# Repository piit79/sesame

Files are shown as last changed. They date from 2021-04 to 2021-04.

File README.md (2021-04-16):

# Sesame

[][cc-by-nc-sa]

### Alice like ergo keyboard using only THT parts



Modified by [u/piit79](https://reddit.com/user/piit79) to use components more in line
with other similar kits (Mysterium etc.).

### Partslist
 |Count|Part|Reference|LCSC Part #|
 |-|-|-|-|
 |1|ATmega32A 40 pin DIP (32L works too)|U1|C12703|
 |1|40 pin DIP socket (optional but highly recommended)|U1|C2332|
 |1|USB4085-GF-A USB Type-C socket|USB1|
 |1|500 mA polyfuse|F1|C369081|
 |2|6mm momentary push buttons|Boot,Reset|C620202|
 |1|16 MHz quartz crystal|XTAL1|C16212|
 |1|4.7 uF electrolytic capacitor|C1|C47879|
 |2|100 nF ceramic disk capacitor|C2,C3|C353913|
 |2|22 pF ceramic disk capacitor|C4,C5|C254096|
 |1|1.5 kΩ resistor|R1|C58620|
 |2|75 Ω resistor|R2,R3|C433693|
 |2|5.1 kΩ resistor|R4,R5|C714593|
 |1|10 kΩ resistor|R6|C119347|
 |2|3.6 V zener diode (DO-35 BZX55C3V6)|D1,D2|C2508|
 |66|universal switching diode (DO-35 1N4148)|D3-D68|C14516|
 
 The USB port can be found here:  
https://www.digikey.com/en/products/detail/gct/USB4085-GF-A/9859733

-----




This work is licensed under a
[Creative Commons Attribution-NonCommercial-ShareAlike 4.0 International License][cc-by-nc-sa].

[][cc-by-nc-sa]

[cc-by-nc-sa]: http://creativecommons.org/licenses/by-nc-sa/4.0/
[cc-by-nc-sa-image]: https://licensebuttons.net/l/by-nc-sa/4.0/88x31.png
[cc-by-nc-sa-shield]: https://img.shields.io/badge/License-CC%20BY--NC--SA%204.0-lightgrey.svg

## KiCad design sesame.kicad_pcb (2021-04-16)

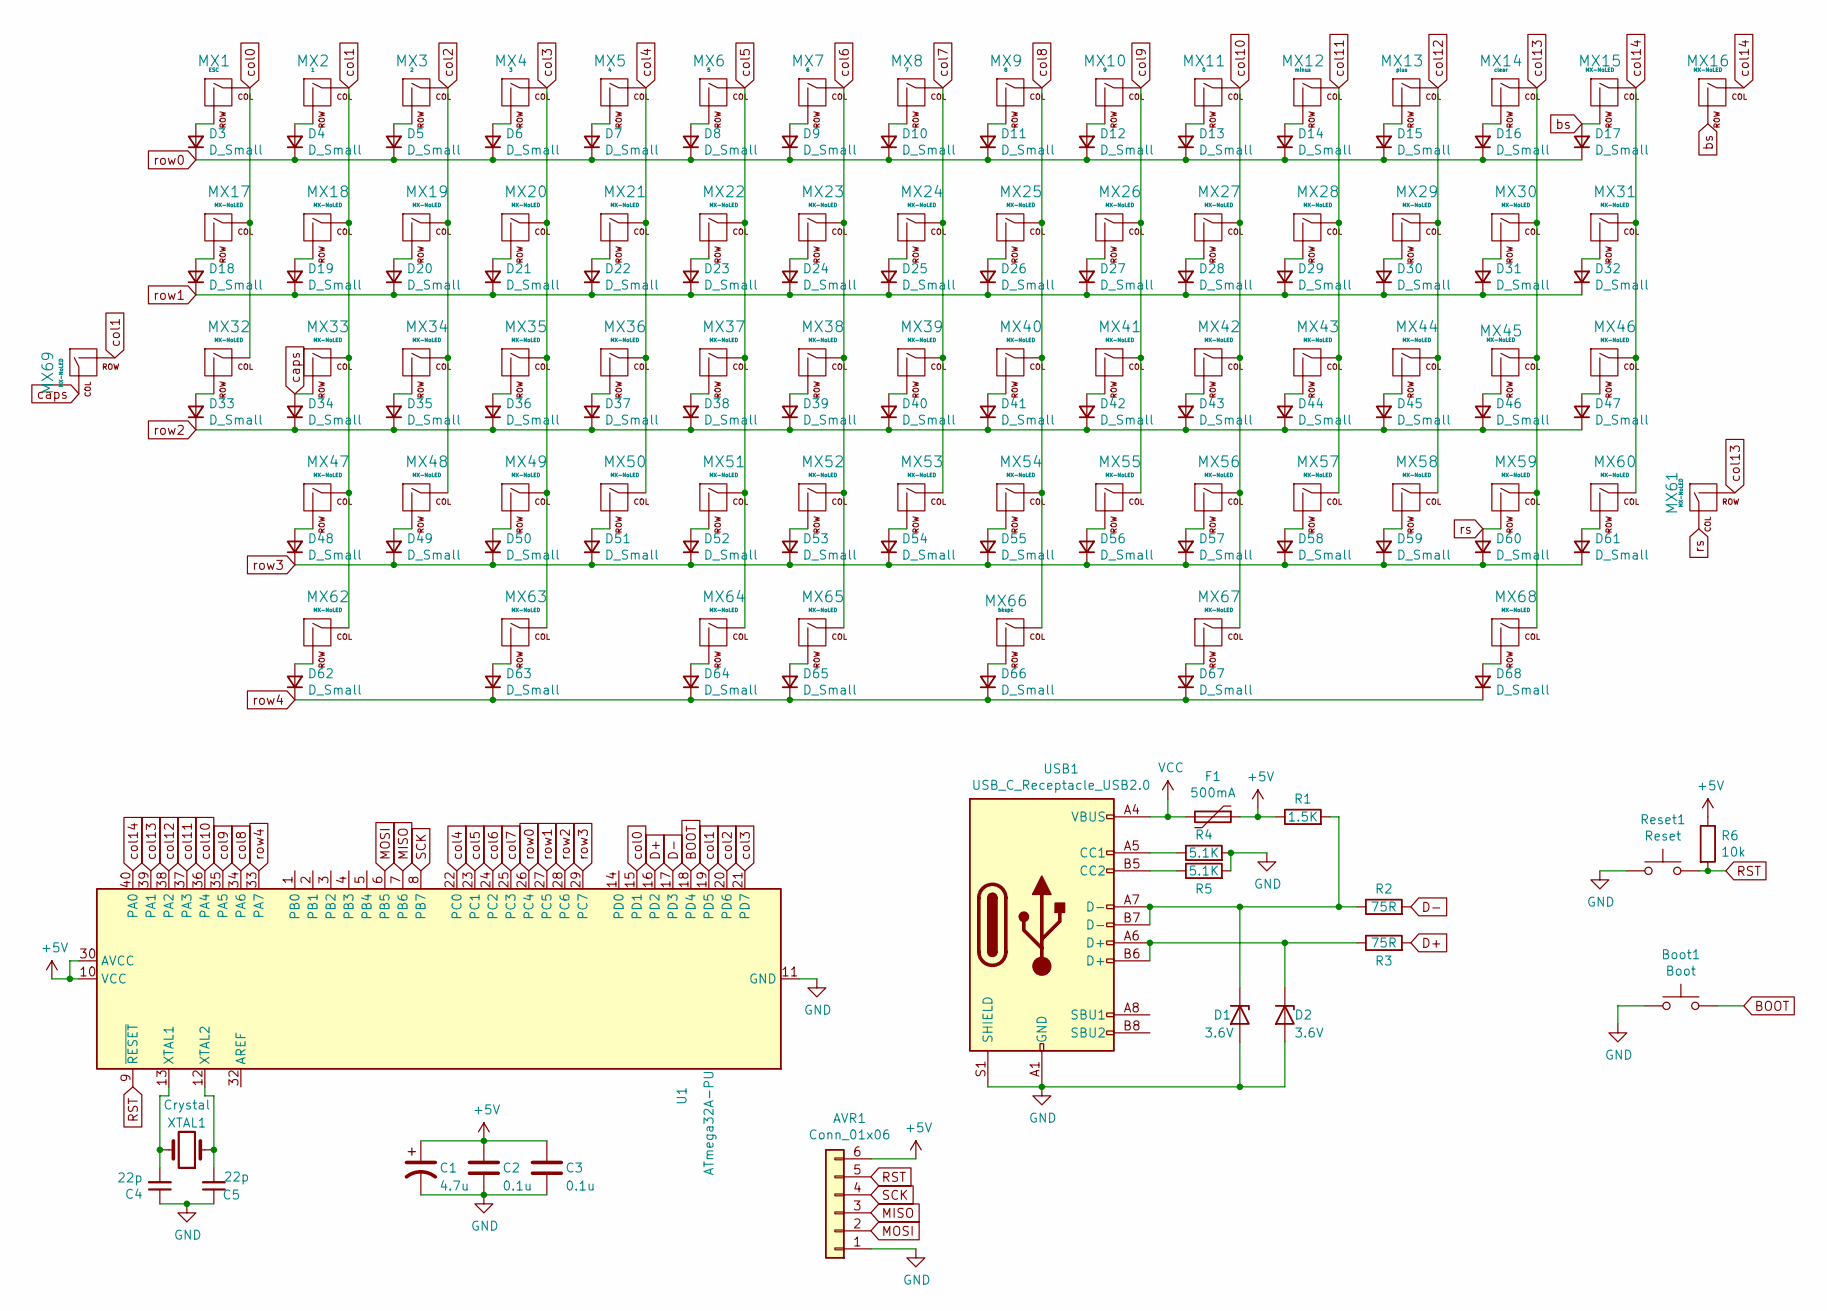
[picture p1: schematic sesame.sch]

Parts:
AVR1: Conn_01x06; PinHeader_1x06_P2.54mm_Vertical
Boot1: Boot; SW_PUSH_6mm
C1: 4.7u; CP_Radial_D4.0mm_P1.50mm
C2, C3: 0.1u; C_Disc_D3.0mm_W2.0mm_P2.50mm
C4, C5: 22p; C_Disc_D6.0mm_W2.5mm_P5.00mm
D1, D2: 3.6V; D_DO-35_SOD27_P7.62mm_Horizontal
D3, D4, D5, D6, D7, D8, D9, D10, D11, D12, D13, D14, D15, D16, D17, D18, D19, D20, D21, D22, D23, D24, D25, D26, D27, D28, D29, D30, D31, D32, D33, D34, D35, D36, D37, D38, D39, D40, D41, D42, D43, D44, D45, D46, D47, D48, D49, D50, D51, D52, D53, D54, D55, D56, D57, D58, D59, D60, D61, D62, D63, D64, D65, D66, D67, D68: D_Small; D_DO-35_SOD27_P7.62mm_Horizontal
F1: 500mA; Fuse_Littelfuse_395Series
MX1: ESC; MXOnly-1U-NoLED
MX2: 1; MXOnly-1U-NoLED
MX3: 2; MXOnly-1U-NoLED
MX4: 3; MXOnly-1U-NoLED
MX5: 4; MXOnly-1U-NoLED
MX6: 5; MXOnly-1U-NoLED
MX7: 6; MXOnly-1U-NoLED
MX8: 7; MXOnly-1U-NoLED
MX9: 8; MXOnly-1U-NoLED
MX10: 9; MXOnly-1U-NoLED
MX11: 0; MXOnly-1U-NoLED
MX12: minus; MXOnly-1U-NoLED
MX13: plus; MXOnly-1U-NoLED
MX14: clear; MXOnly-1U-NoLED
MX15: MX-NoLED; MXOnly-2U-NoLED
MX16, MX17, MX19, MX20, MX21, MX22, MX23, MX24, MX25, MX26, MX27, MX28, MX29, MX30, MX32, MX34, MX35, MX36, MX37, MX38, MX39, MX40, MX41, MX42, MX43, MX44, MX45, MX48, MX49, MX50, MX51, MX52, MX53, MX54, MX55, MX56, MX57, MX58, MX60, MX62, MX63, MX67, MX68: MX-NoLED; MXOnly-1U-NoLED
MX18, MX31: MX-NoLED; MXOnly-1.5U-NoLED
MX33, MX59: MX-NoLED; MXOnly-1.75U-NoLED
MX46: MX-NoLED; MXOnly-2.25U-ReversedStabilizers-NoLED
MX47: MX-NoLED; MXOnly-2.25U-NoLED
MX61: MX-NoLED; MXOnly-2.75U-NoLED
MX64: MX-NoLED; MXOnly-2U-ReversedStabilizers-NoLED
MX65, MX69: MX-NoLED; MXOnly-1.25U-NoLED
MX66: bkspc; MXOnly-2.25U-ReversedStabilizers-NoLED
R1: 1.5K; R_Axial_DIN0207_L6.3mm_D2.5mm_P10.16mm_Horizontal
R2, R3: 75R; R_Axial_DIN0207_L6.3mm_D2.5mm_P10.16mm_Horizontal
R4, R5: 5.1K; R_Axial_DIN0207_L6.3mm_D2.5mm_P10.16mm_Horizontal
R6: 10k; R_Axial_DIN0207_L6.3mm_D2.5mm_P10.16mm_Horizontal
Reset1: Reset; SW_PUSH_6mm
U1: ATmega32A-PU; DIP-40_W15.24mm
USB1: USB_C_Receptacle_USB2.0; USB_C_GCT_USB4085
XTAL1: Crystal; Crystal_HC49-4H_Vertical

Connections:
+5V: AVR1.6, C1.1, C2.1, C3.1, F1.1, R1.1, R6.1, U1.10 (VCC), U1.30 (AVCC)
BOOT: Boot1.2, U1.18 (PD4)
D+: R3.2, U1.16 (PD2)
D-: R2.2, U1.17 (PD3)
GND: AVR1.1, Boot1.1, C1.2, C2.2, C3.2, C4.1, C5.1, D1.2 (A), D2.2 (A), R4.2, R5.2, Reset1.1, U1.11 (GND), U1.31 (GND), USB1.A1 (GND), USB1.A12 (GND), USB1.B1 (GND), USB1.B12 (GND), USB1.S1 (SHIELD)
MISO: AVR1.3, U1.7 (PB6)
MOSI: AVR1.2, U1.6 (PB5)
unnamed: C4.2, U1.13 (XTAL1), XTAL1.2
unnamed: C5.2, U1.12 (XTAL2), XTAL1.1
unnamed: D1.1 (K), R1.2, R2.1, USB1.A7 (D-), USB1.B7 (D-)
unnamed: D2.1 (K), R3.1, USB1.A6 (D+), USB1.B6 (D+)
unnamed: D3.2 (A), MX1.2 (ROW)
unnamed: D4.2 (A), MX2.2 (ROW)
unnamed: D5.2 (A), MX3.2 (ROW)
unnamed: D6.2 (A), MX4.2 (ROW)
unnamed: D7.2 (A), MX5.2 (ROW)
unnamed: D8.2 (A), MX6.2 (ROW)
unnamed: D9.2 (A), MX7.2 (ROW)
unnamed: D10.2 (A), MX8.2 (ROW)
unnamed: D11.2 (A), MX9.2 (ROW)
unnamed: D12.2 (A), MX10.2 (ROW)
unnamed: D13.2 (A), MX11.2 (ROW)
unnamed: D14.2 (A), MX12.2 (ROW)
unnamed: D15.2 (A), MX13.2 (ROW)
unnamed: D16.2 (A), MX14.2 (ROW)
unnamed: D18.2 (A), MX17.2 (ROW)
unnamed: D19.2 (A), MX18.2 (ROW)
unnamed: D20.2 (A), MX19.2 (ROW)
unnamed: D21.2 (A), MX20.2 (ROW)
unnamed: D22.2 (A), MX21.2 (ROW)
unnamed: D23.2 (A), MX22.2 (ROW)
unnamed: D24.2 (A), MX23.2 (ROW)
unnamed: D25.2 (A), MX24.2 (ROW)
unnamed: D26.2 (A), MX25.2 (ROW)
unnamed: D27.2 (A), MX26.2 (ROW)
unnamed: D28.2 (A), MX27.2 (ROW)
unnamed: D29.2 (A), MX28.2 (ROW)
unnamed: D30.2 (A), MX29.2 (ROW)
unnamed: D31.2 (A), MX30.2 (ROW)
unnamed: D32.2 (A), MX31.2 (ROW)
unnamed: D33.2 (A), MX32.2 (ROW)
unnamed: D35.2 (A), MX34.2 (ROW)
unnamed: D36.2 (A), MX35.2 (ROW)
unnamed: D37.2 (A), MX36.2 (ROW)
unnamed: D38.2 (A), MX37.2 (ROW)
unnamed: D39.2 (A), MX38.2 (ROW)
unnamed: D40.2 (A), MX39.2 (ROW)
unnamed: D41.2 (A), MX40.2 (ROW)
unnamed: D42.2 (A), MX41.2 (ROW)
unnamed: D43.2 (A), MX42.2 (ROW)
unnamed: D44.2 (A), MX43.2 (ROW)
unnamed: D45.2 (A), MX44.2 (ROW)
unnamed: D46.2 (A), MX45.2 (ROW)
unnamed: D47.2 (A), MX46.2 (ROW)
unnamed: D48.2 (A), MX47.2 (ROW)
unnamed: D49.2 (A), MX48.2 (ROW)
unnamed: D50.2 (A), MX49.2 (ROW)
unnamed: D51.2 (A), MX50.2 (ROW)
unnamed: D52.2 (A), MX51.2 (ROW)
unnamed: D53.2 (A), MX52.2 (ROW)
unnamed: D54.2 (A), MX53.2 (ROW)
unnamed: D55.2 (A), MX54.2 (ROW)
unnamed: D56.2 (A), MX55.2 (ROW)
unnamed: D57.2 (A), MX56.2 (ROW)
unnamed: D58.2 (A), MX57.2 (ROW)
unnamed: D59.2 (A), MX58.2 (ROW)
unnamed: D61.2 (A), MX60.2 (ROW)
unnamed: D62.2 (A), MX62.2 (ROW)
unnamed: D63.2 (A), MX63.2 (ROW)
unnamed: D64.2 (A), MX64.2 (ROW)
unnamed: D65.2 (A), MX65.2 (ROW)
unnamed: D66.2 (A), MX66.2 (ROW)
unnamed: D67.2 (A), MX67.2 (ROW)
unnamed: D68.2 (A), MX68.2 (ROW)
unnamed: R4.1, USB1.A5 (CC1)
unnamed: R5.1, USB1.B5 (CC2)
RST: AVR1.5, R6.2, Reset1.2, U1.9 (~RESET)
SCK: AVR1.4, U1.8 (PB7)
VCC: F1.2, USB1.A4 (VBUS), USB1.A9 (VBUS), USB1.B4 (VBUS), USB1.B9 (VBUS)
bs: D17.2 (A), MX15.2 (ROW), MX16.2 (ROW)
caps: D34.2 (A), MX33.2 (ROW), MX69.1 (COL)
col0: MX1.1 (COL), MX17.1 (COL), MX32.1 (COL), U1.15 (PD1)
col1: MX2.1 (COL), MX18.1 (COL), MX33.1 (COL), MX47.1 (COL), MX62.1 (COL), MX69.2 (ROW), U1.19 (PD5)
col2: MX3.1 (COL), MX19.1 (COL), MX34.1 (COL), MX48.1 (COL), U1.20 (PD6)
col3: MX4.1 (COL), MX20.1 (COL), MX35.1 (COL), MX49.1 (COL), MX63.1 (COL), U1.21 (PD7)
col4: MX5.1 (COL), MX21.1 (COL), MX36.1 (COL), MX50.1 (COL), U1.22 (PC0)
col5: MX6.1 (COL), MX22.1 (COL), MX37.1 (COL), MX51.1 (COL), MX64.1 (COL), U1.23 (PC1)
col6: MX7.1 (COL), MX23.1 (COL), MX38.1 (COL), MX52.1 (COL), MX65.1 (COL), U1.24 (PC2)
col7: MX8.1 (COL), MX24.1 (COL), MX39.1 (COL), MX53.1 (COL), U1.25 (PC3)
col8: MX9.1 (COL), MX25.1 (COL), MX40.1 (COL), MX54.1 (COL), MX66.1 (COL), U1.34 (PA6)
col9: MX10.1 (COL), MX26.1 (COL), MX41.1 (COL), MX55.1 (COL), U1.35 (PA5)
col10: MX11.1 (COL), MX27.1 (COL), MX42.1 (COL), MX56.1 (COL), MX67.1 (COL), U1.36 (PA4)
col11: MX12.1 (COL), MX28.1 (COL), MX43.1 (COL), MX57.1 (COL), U1.37 (PA3)
col12: MX13.1 (COL), MX29.1 (COL), MX44.1 (COL), MX58.1 (COL), U1.38 (PA2)
col13: MX14.1 (COL), MX30.1 (COL), MX45.1 (COL), MX59.1 (COL), MX61.2 (ROW), MX68.1 (COL), U1.39 (PA1)
col14: MX15.1 (COL), MX16.1 (COL), MX31.1 (COL), MX46.1 (COL), MX60.1 (COL), U1.40 (PA0)
row0: D3.1 (K), D4.1 (K), D5.1 (K), D6.1 (K), D7.1 (K), D8.1 (K), D9.1 (K), D10.1 (K), D11.1 (K), D12.1 (K), D13.1 (K), D14.1 (K), D15.1 (K), D16.1 (K), D17.1 (K), U1.26 (PC4)
row1: D18.1 (K), D19.1 (K), D20.1 (K), D21.1 (K), D22.1 (K), D23.1 (K), D24.1 (K), D25.1 (K), D26.1 (K), D27.1 (K), D28.1 (K), D29.1 (K), D30.1 (K), D31.1 (K), D32.1 (K), U1.27 (PC5)
row2: D33.1 (K), D34.1 (K), D35.1 (K), D36.1 (K), D37.1 (K), D38.1 (K), D39.1 (K), D40.1 (K), D41.1 (K), D42.1 (K), D43.1 (K), D44.1 (K), D45.1 (K), D46.1 (K), D47.1 (K), U1.28 (PC6)
row3: D48.1 (K), D49.1 (K), D50.1 (K), D51.1 (K), D52.1 (K), D53.1 (K), D54.1 (K), D55.1 (K), D56.1 (K), D57.1 (K), D58.1 (K), D59.1 (K), D60.1 (K), D61.1 (K), U1.29 (PC7)
row4: D62.1 (K), D63.1 (K), D64.1 (K), D65.1 (K), D66.1 (K), D67.1 (K), D68.1 (K), U1.33 (PA7)
rs: D60.2 (A), MX59.2 (ROW), MX61.1 (COL)

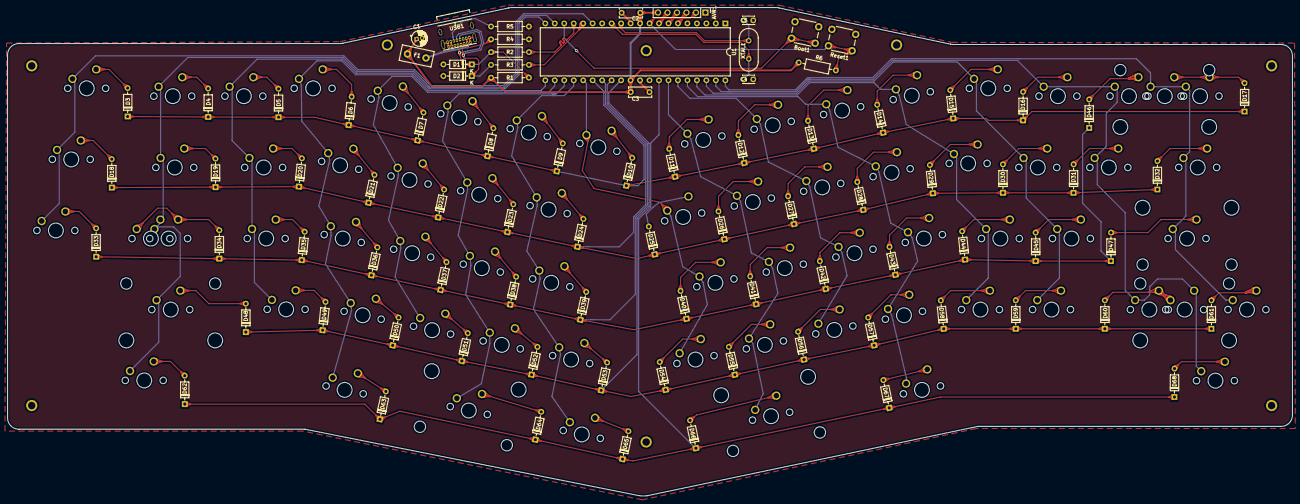
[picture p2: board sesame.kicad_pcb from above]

Board: 2 copper layers, 344.4 x 130.9 mm, 155 parts (0 on the bottom side), 102 nets.

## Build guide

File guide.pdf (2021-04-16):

## Sesame Ergo build guide

Very quick and dirty build guide. Modified by piit79.
If you need any help feel free to contact me on Discord (piit79#2997) or on Reddit (u/piit79).

### Parts included:

1 | Sesame PCB
1 | Sesame Backplate (Logo on the back)
1 | Sesame FR4 switchplate
1 | Acrylic cover window
1 | Backplate foam (optional)
14 | M2x4 mm screws for the backplate and window standoffs
2 | M2x6 mm screws for the acrylic window
6 | M2x6 standoffs for the backplate
2 | M2x10 standoffs for the acrylic window
1 | ATmega32A controller
1 | 40 pin DIP socket (optional but highly recommended)
1 | USB Type-C socket (USB4085-GF-A)
1 | 500 mA polyfuse
2 | 6mm momentary push buttons
1 | 16 MHz quartz crystal
1 | 4.7 uF electrolytic capacitor
2 | 100 nF ceramic disk capacitor
2 | 22 pF ceramic disk capacitor
1 | 10 kΩ resistor
1 | 1.5 kΩ resistor
2 | 75 Ω resistor
2 | 5.1 kΩ resistor
2 | 3.6 V zener diode (DO-35 BZX55C3V6)
68 | universal switching diode (DO-35 1N4148)

You only need 66 of the switching diodes for the board. The rest are replacements in case one gets damaged during soldering.

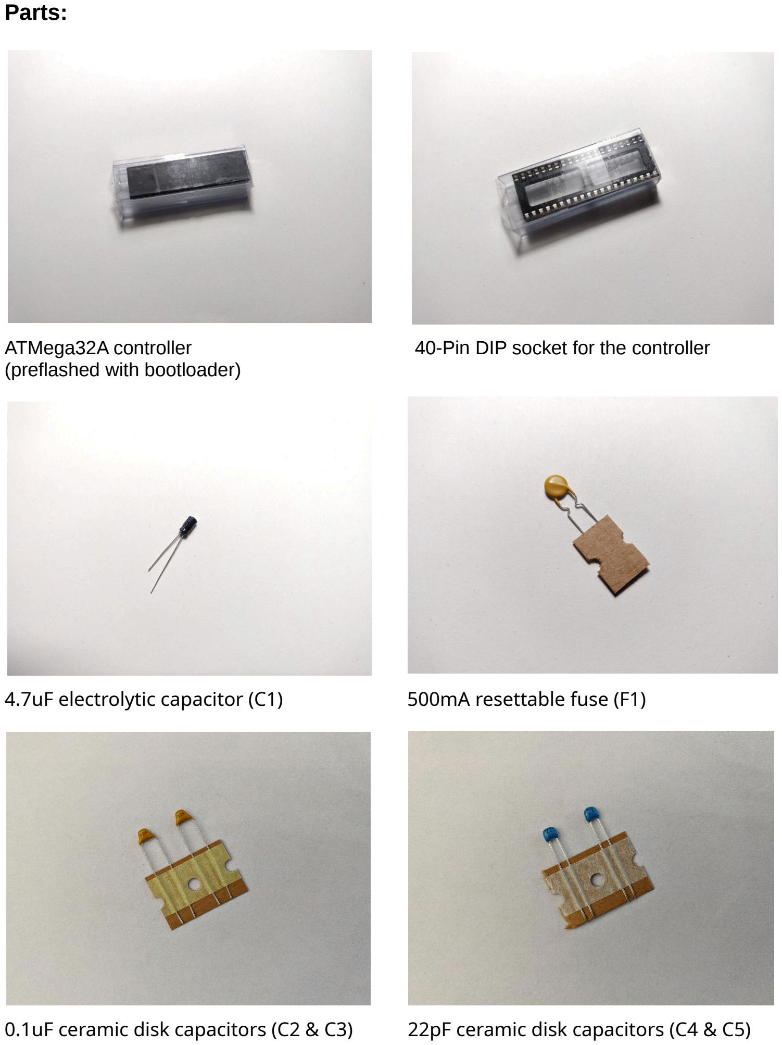
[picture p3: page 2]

Parts:

ATMega32A controller | 40-Pin DIP socket for the controller
(preflashed with bootloader)
4.7uF electrolytic capacitor (C1) | 500mA resettable fuse (F1)
0.1uF ceramic disk capacitors (C2 & C3) | 22pF ceramic disk capacitors (C4 & C5)

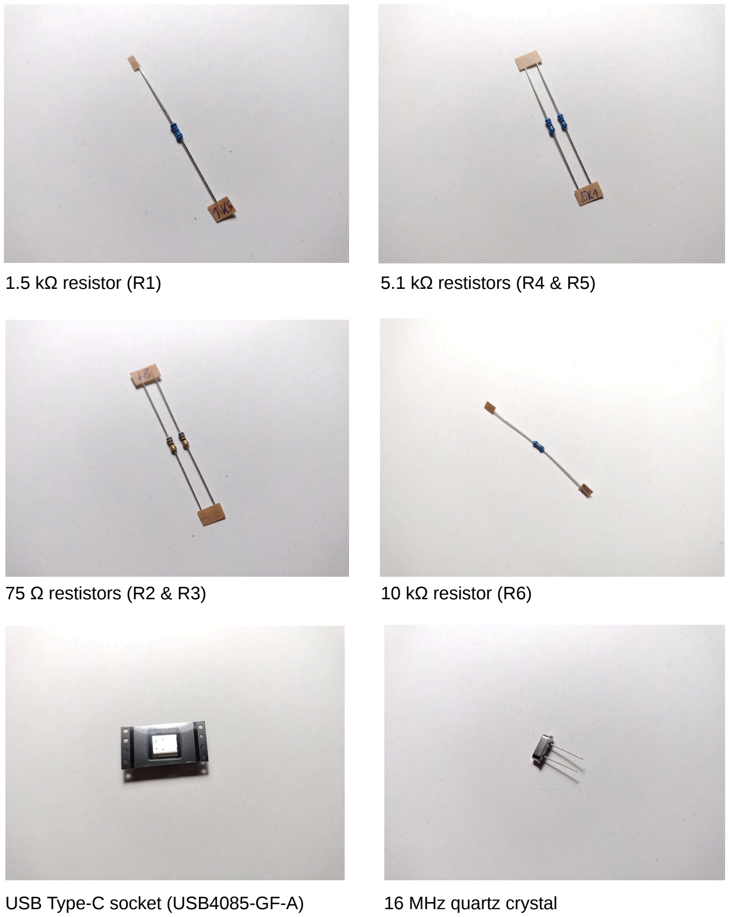
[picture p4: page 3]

1.5 kΩ resistor (R1) | 5.1 kΩ restistors (R4 & R5)
75 Ω restistors (R2 & R3) | 10 kΩ resistor (R6)
USB Type-C socket (USB4085-GF-A) | 16 MHz quartz crystal

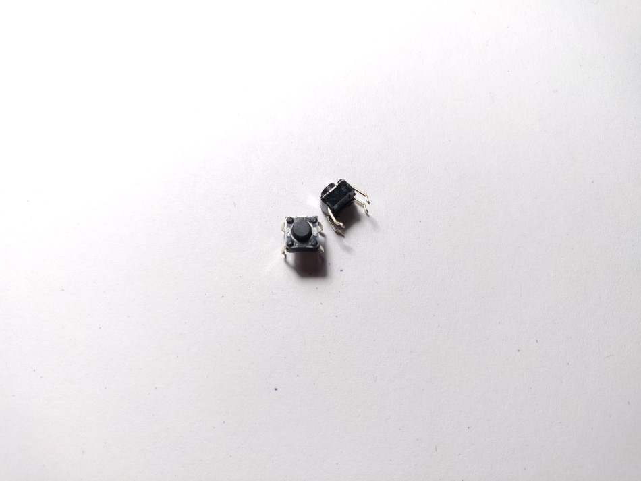
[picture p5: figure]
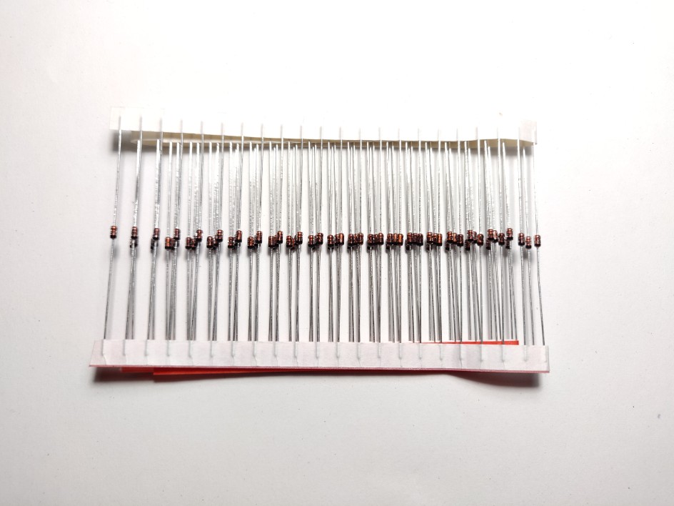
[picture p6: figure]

6mm pushbuttons (reset & boot) | universal switching diodes (80x)

### Building the PCB:

1. Start with the USB-C port as this is the most complicated part to solder in this kit.
Put in the port and secure it in place with some electrical tape.
Next put on some flux over the pins on the bottom of the PCB.
Melt some solder on the tip of your iron and carefully drag the iron tip with the solder over the pins. The solder should stick to the pins without creating any bridges between them if you used enough flux.
If you don‘t get it right on the first try remove the solder with some whick and try it again. It‘s important that there are absolutely no shorts between the contacts. Otherwise the board will not work.
2. Next should be the controller socket. Put it in with the cutout nose like it‘s shown on the PCB silkscreen. Hold it in place with some electrical tape on top of the board. Solder every second pin on the board to prevent overheating the plastic. Then do the rest of the pins.
3. Solder in the quartz crystal into it‘s spot next to the controller (XTAL1). Polarity doesn‘t matter here. Do not pull hard on the parts legs as this can damage the part.

### 4. Solder in the capacitors. The values are as follows:

- C1 (Electrolytic! Watch the polarity! white side = negative) = 4.7 uF
- C2 & C3 (next to the controller socket) = 0.1 uF
- C4 & C5 (left and right of the crystal) = 22 pF

### 5. Next up are the two 3.6V Zener diodes (ZD). They go into the spots D1 and D2. Watch

the polarity! The white line on the silkscreen has to match with the black or white line on the diode.
These are special diodes! They can not be exchanged with the standard switching diodes! Make sure that you are using the correct ones.
They are labeled 3V6 on their side. The switching diodes don‘t have that label.

### 6. Now come the resistors. Their values are as follows:

- R1 = 1.5 kΩ
- R2 & R3 = 75 Ω
- R4 & R5 = 5.1 kΩ
- R6 (next to the buttons) = 10 kΩ

### 7. Solder in the rest of the parts:

- the 500 mA polyfuse (spot F1)
- the boot and reset pushbuttons
- the contacts labeled „AVR“ above the controller are left empty

### 8. Finish the board by soldering in all 66 diodes. Watch the polarity (white stripe)!

9. Lastly put the controller into the socket. Make sure that the indentation on the controller matches with the indentation in the socket! If you put it in the wrong way round it can destroy the controller.
Press it down firmly so that it sits flush with the socket. Take care to not bend any legs.

### Assembly guide:

1. Start with the standoffs for the backplate.
Put in the standoffs (M2x4) from the bottom through the PCB and screw them in place with the M2 nuts.
2. Screw in the standoffs for the acrylic window.
Put the standoffs (M2x10) in from the front of the PCB and screw them in place with the M2 nuts on the back side.

### 3. Next put the included foam on the back of the PCB. The holes should align with the

standoffs. If it doesn‘t fit turn it around. It only fits on one way because the PCB is not perfectly symmetrical (even though it might look like it is).

4. Attach the backplate to the standoffs using the M2 screws.
(On this revision the topmost screw, the one below the controller, won‘t fit unfortunately due to a stupid change that I only made to the PCB and not to the backplate)
5. Screw on the acrylic window. Remove the protective foil on both sides first.

### Building and flashing the bootloader:

### If you bought the kit from me the controller is already flashed with the bootloader. You can skip this step!

Download the bootloader firmware from here: https://github.com/kb-elmo/sesame/tree/master/firmware/bootloader

You need either a Linux system or MingW on Windows for this as this requires compiling some stuff.

The firmware is already set up and you don‘t need to change anything in the configuration files for this board.

### 1. Build the bootloader firmware by running „make“ on your console

### 2. Make sure that you can reach the controller by executing a chip erase with

„avrude -c usbasp -p m32 -e“ (you have to run these commands as root in Linux)

### 3. Flash the firmware on the controller with „make flash“

### 4. Set the controller fuses to the correct values „make fuse“

### 5. Finally lock the controller bootloader in place with „make lock“

The avrdude tool should show a „success“ after each operation. If the flashing process was successful you can unplug the ASP flasher and plug in the USB now.

### Building and flashing QMK:

The keyboard can be found on https://config.qmk.fm if you want to configure a static keymap or you can use VIA. I recommend the latter.

For VIA download the firmware for the board and the client from: https://caniusevia.com

Flash the firmware on the board using the QMK Toolbox which can be found here: https://github.com/qmk/qmk_toolbox/releases

To put the board into controller into bootloader mode press and hold down the boot button and tap the reset button once. Then let loose of the boot button.
The board should show up in your OS as a „USBasp“ device (or similar).
After the flashing process was successfull hit the reset button once to get into normal keyboard mode again.

You can of course also build the firmware yourself if you prefer that.
The code for this can be found in the QMK repository in keyboards/kb-elmo/sesame. I‘m not going into the details of this here

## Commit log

2021-04-16 Use components more in line with other similar kits (Mysterium etc.)
    [sesame-B_Cu.gbr, sesame-B_Mask.gbr, sesame-B_SilkS.gbr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]
2021-04-16 Add gerber zip files

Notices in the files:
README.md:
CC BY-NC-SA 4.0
